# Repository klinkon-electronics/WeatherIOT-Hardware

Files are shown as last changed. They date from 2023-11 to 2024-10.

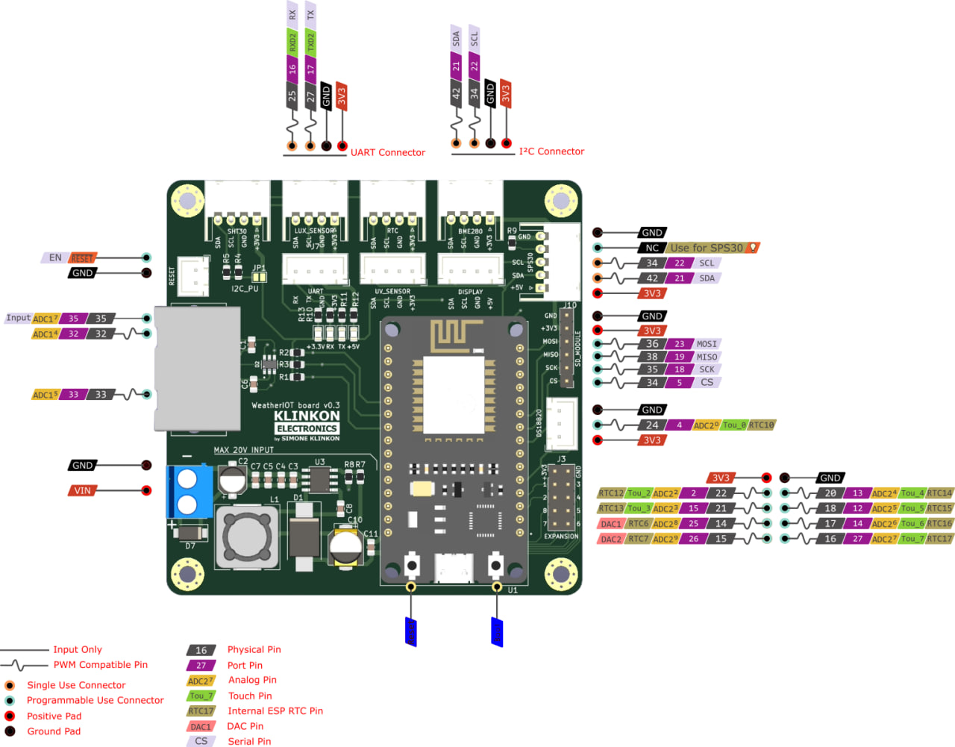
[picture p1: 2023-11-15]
WeatherIOT_0.3/pinoutWI.jpg

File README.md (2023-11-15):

# WeatherIOT-Hardware
Official repository about WeatherIOT Board and derivates (for example boards based on same hardware but with different layouts or sensors onboard)
Please contact Simone at klinkonelectronics@gmail.com or @Simoste1969 on telegram for asking mods or to upload new boards 

List of current boards:

WeatherIOT 0.3: Initial release of the board, implementing connectors for all kind of sensors, including sparkfun weather meter (anemometer and pluviometer), on board buck converter power supply (max 30V input) and ESD Protection

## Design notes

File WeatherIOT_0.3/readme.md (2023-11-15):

This is first public release of the WeatherIOT hardware

Here you can find schematics and gerbers about our full open source meteorological node, that you can use to control greenhouses, beehives, smart sprinklers, and much more, and monitoring enviroment with classic sensors as BME680, DS18B20, DHT22, and so on. Please refer to pinout of ESP32 devkit v1 to know the relative pin in the board from the pinout image. You can always contact us at klinkonelectronics@gmail.com

The interactive Bom will help you to understand position of the components and the list of materials needed to assembly the board

Here the schematic, feel free to edit that and upload your edited version in this Git repo:


second sheet about leds and expansion board


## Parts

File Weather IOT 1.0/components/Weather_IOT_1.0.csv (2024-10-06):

Reference | Value | Footprint | LCSC | LCSC-2 | Qty | DNP
C1,C4,C5 | 4.7u | Capacitor_SMD:C_0603_1608Metric | C307467 |  | 3
C2,C9,C13,C16,C18,C19 | 10u | Capacitor_SMD:C_0603_1608Metric | C96446 |  | 6
C3,C10,C11,C14,C17 | 22u | Capacitor_SMD:C_0603_1608Metric | C86295 |  | 5
C6,C7,C20,C23,C24,C25,C26,C27,C28 | 100n | Capacitor_SMD:C_0603_1608Metric | C282519 |  | 9
C8 | 120p | Capacitor_SMD:C_0603_1608Metric | C282671 |  | 1
C12 | 22n | Capacitor_SMD:C_0603_1608Metric | C21122 |  | 1
C15 | 100p | Capacitor_SMD:C_0603_1608Metric | C525236 |  | 1
C21,C22 | 1uF | Capacitor_SMD:C_0603_1608Metric | C1592 |  | 2
D1,D8 | SS34 | Diode_SMD:D_SMA | C8678 |  | 2
D2,D3 | SM4007PL | Diode_SMD:D_SOD-123F | C3008060 |  | 2
D4 | USB-CHRG | LED_SMD:LED_0805_2012Metric | C965812 |  | 1
D5 | USB-DONE | LED_SMD:LED_0805_2012Metric | C965815 |  | 1
D6 | PWR_5V | LED_SMD:LED_0805_2012Metric | C965812 |  | 1
D7 | PWR_3V3 | LED_SMD:LED_0805_2012Metric | C965812 |  | 1
D9 | RX | LED_SMD:LED_0805_2012Metric | C965813 |  | 1
D10 | TX | LED_SMD:LED_0805_2012Metric | C965813 |  | 1
D11 | DT1042-04SO-7 | _My_ic:DT1042-04SO-7 | C460064 |  | 1
D12 | CUS10S30 | Diode_SMD:D_SOD-323_HandSoldering | C146335 |  | 1
J1 | PV BOARD | Connector_PinSocket_2.54mm:PinSocket_1x05_P2.54mm_Vertical | C492404 |  | 1
J2 | 1S Battery 1 | Connector_JST:JST_XH_B2B-XH-A_1x02_P2.50mm_Vertical | C158012 |  | 1
J3 | Vin5-24V/12VFV | TerminalBlock:TerminalBlock_bornier-2_P5.08mm | C709041 |  | 1
J4 | RESET | Connector_JST:JST_XH_S2B-XH-A_1x02_P2.50mm_Horizontal | C157931 |  | 1
J5 | Wind sense | _MIA:R-RJ11R04P-A801 | C189746 |  | 1
J6 | Rain sense | _MIA:R-RJ11R04P-A801 | C189746 |  | 1
J7 | SD_module | Connector_PinHeader_2.54mm:PinHeader_1x06_P2.54mm_Horizontal | C7501615 |  | 1
J8,J10 | DS18B20 | Connector_JST:JST_XH_B3B-XH-A_1x03_P2.50mm_Vertical | C161870 |  | 2
J9 | to Expansion Board | Connector_PinSocket_2.54mm:PinSocket_1x05_P2.54mm_Vertical | C492404 |  | 1
J11 | RTC | Connector_JST:JST_XH_S4B-XH-A_1x04_P2.50mm_Horizontal | C157925 |  | 1
J12 | BME280 | Connector_JST:JST_XH_S4B-XH-A_1x04_P2.50mm_Horizontal | C157925 |  | 1
J13 | SPS30 | Connector_JST:JST_XH_S5B-XH-A_1x05_P2.50mm_Horizontal | C157925 |  | 1
J14 | Display | Connector_JST:JST_XH_S4B-XH-A_1x04_P2.50mm_Horizontal | C157925 |  | 1
J15 | EXT_UART2 | Connector_JST:JST_XH_S4B-XH-A_1x04_P2.50mm_Horizontal | C157925 |  | 1
J16 | EXPANSION_PORT | Connector_PinHeader_2.54mm:PinHeader_2x05_P2.54mm_Horizontal | C5383093 |  | 1
JP2 | no_BATT | Connector_PinHeader_2.54mm:PinHeader_1x02_P2.54mm_Vertical | C492401 | C2998928 | 1
L1 | 2.2u | Inductor_SMD:L_Chilisin_BMRA00040420 | C167206 |  | 1
L2 | 1uH | Inductor_SMD:L_Taiyo-Yuden_NR-24xx | C307851 |  | 1
R1,R4 | 100k | Resistor_SMD:R_0603_1608Metric_Pad0.98x0.95mm_HandSolder | C3016388 |  | 2
R2,R3,R7,R8,R12,R14,R15,R16,R17,R20,R21 | 1k | Resistor_SMD:R_0603_1608Metric_Pad0.98x0.95mm_HandSolder | C3016283 |  | 11
R5 | 22k | Resistor_SMD:R_0603_1608Metric_Pad0.98x0.95mm_HandSolder | C2907128 |  | 1
R6 | 30k | Resistor_SMD:R_0603_1608Metric_Pad0.98x0.95mm_HandSolder | C2907025 |  | 1
R9,R10 | 1M | Resistor_SMD:R_0603_1608Metric_Pad0.98x0.95mm_HandSolder | C3016422 |  | 2
R11 | 33k | Resistor_SMD:R_0603_1608Metric_Pad0.98x0.95mm_HandSolder | C2907028 |  | 1
R18 | 4.7k | Resistor_SMD:R_0603_1608Metric_Pad0.98x0.95mm_HandSolder | C2907034 |  | 1
R19,R22 | 10k | Resistor_SMD:R_0603_1608Metric_Pad0.98x0.95mm_HandSolder | C103199 |  | 2
U1 | TPS62A01A | Package_TO_SOT_SMD:SOT-563 | C5157937 |  | 1
U2 | TP4056 | Package_SO:HTSOP-8-1EP_3.9x4.9mm_P1.27mm_EP2.4x3.2mm_ThermalVias | C382139 |  | 1
U3 | MAX25239AFFA_VY+ | _My_ic:MAX25239AFFA_VY+ |  |  | 1
U4 | Wemos_esp32_mini | _My_boards:ESP32_mini |  |  | 1

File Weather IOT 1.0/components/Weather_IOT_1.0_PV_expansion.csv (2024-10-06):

Reference | Value | Footprint | LCSC | Qty | DNP
C1 | 330u | Capacitor_THT:CP_Radial_D8.0mm_P3.50mm | C357626 | 1
C2,C7 | 1u | Capacitor_SMD:C_0603_1608Metric | C15849 | 2
C3,C4 | 100n | Capacitor_SMD:C_0603_1608Metric | C282519 | 2
C5 | 220n | Capacitor_SMD:C_0603_1608Metric | C64705 | 1
C6 | 10u | Capacitor_SMD:C_0603_1608Metric | C96446 | 1
D1 | CHRG | LED_SMD:LED_0805_2012Metric | C965812 | 1
D2 | DONE | LED_SMD:LED_0805_2012Metric | C965815 | 1
D3,D4 | SK84 | Diode_SMD:D_SMB | C2922187 | 2
J1 | to WIoT | Connector_PinHeader_2.54mm:PinHeader_1x05_P2.54mm_Vertical | C492404 | 1
L1 | 100uH | Inductor_SMD:L_TaiTech_TMPC1265_13.5x12.5mm | C357118 | 1
Q1 | HYG210P06LQ1D | Package_TO_SOT_SMD:TO-252-2_TabPin1 | C2834760 | 1
R1 | 4.7k | Resistor_SMD:R_0603_1608Metric | C2907034 | 1
R2 | 1k | Resistor_SMD:R_0603_1608Metric | C3016283 | 1
R3 | 120 | Resistor_SMD:R_0603_1608Metric | C2906988 | 1
R4 | 120m | Resistor_SMD:R_2010_5025Metric | C3000625 | 1
RV1 | 100k | Potentiometer_THT:Potentiometer_Bourns_3296W_Vertical | C48084 | 1
U1 | CN3791 | Package_SO:SSOP-10_3.9x4.9mm_P1.00mm | C154992 | 1

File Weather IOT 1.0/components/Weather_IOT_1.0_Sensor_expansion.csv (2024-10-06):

Reference | Value | Footprint | LCSC | Qty | DNP
C6,C9 | 10u | Capacitor_SMD:C_0603_1608Metric | C96446 | 2
C8,C10 | 100n | Capacitor_SMD:C_0603_1608Metric | C282519 | 2
D1 | PWR_5V | LED_SMD:LED_0805_2012Metric | C965812 | 1
D2 | PWR_3V3 | LED_SMD:LED_0805_2012Metric | C965812 | 1
H1,H2 | MountingHole | MountingHole:MountingHole_3.2mm_M3_Pad_Via |  | 2 | DNP
J1 | LUX_Sensor | Connector_JST:JST_XH_S4B-XH-A_1x04_P2.50mm_Horizontal | C157925 | 1
J2,J5,J7 | I2C_3V3 | Connector_JST:JST_XH_B4B-XH-A_1x04_P2.50mm_Vertical | C161871 | 3
J3 | to WIoT | Connector_PinHeader_2.54mm:PinHeader_1x05_P2.54mm_Vertical |  | 1
J4 | UV_Sensor | Connector_JST:JST_XH_S4B-XH-A_1x04_P2.50mm_Horizontal | C157925 | 1
J6 | SHT30 (soil) | Connector_JST:JST_XH_S4B-XH-A_1x04_P2.50mm_Horizontal | C157925 | 1
J8 | I2C_5V | Connector_JST:JST_XH_S4B-XH-A_1x04_P2.50mm_Horizontal | C157925 | 1
J9 | I2C_5V | Connector_JST:JST_XH_B4B-XH-A_1x04_P2.50mm_Vertical | C161871 | 1
R1,R2 | 1k | Resistor_SMD:R_0603_1608Metric_Pad0.98x0.95mm_HandSolder | C3016283 | 2

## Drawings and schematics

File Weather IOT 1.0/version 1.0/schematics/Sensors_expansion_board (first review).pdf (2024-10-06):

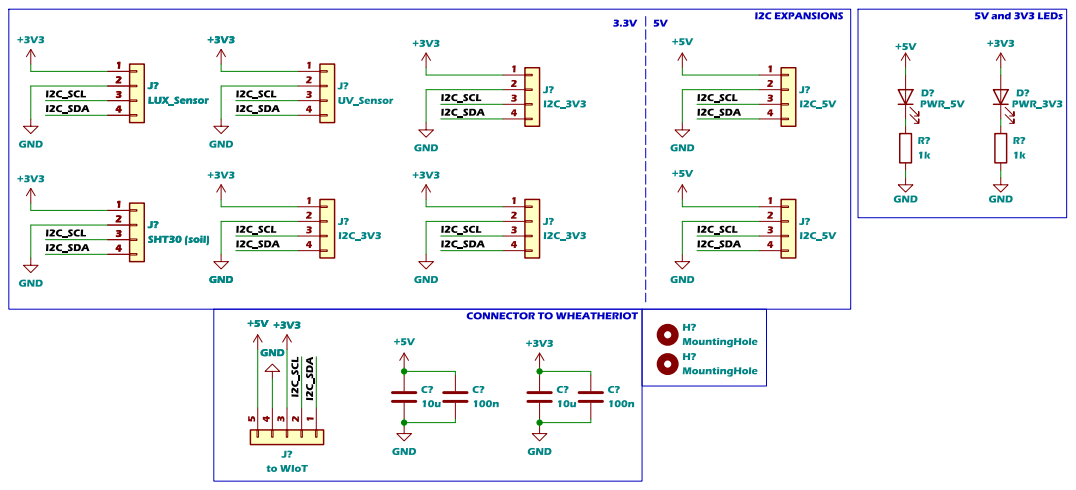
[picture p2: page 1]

5V and 3V3 LEDs 3.3V CONNECTOR TO WHEATHERIOT

File: Sensors_expansion_board.kicad_sch Sheet: / Klinkon Electronics & Floppy Lab

Id: 1/1 Title: Sensors expansion board WeatherIOT 1.0

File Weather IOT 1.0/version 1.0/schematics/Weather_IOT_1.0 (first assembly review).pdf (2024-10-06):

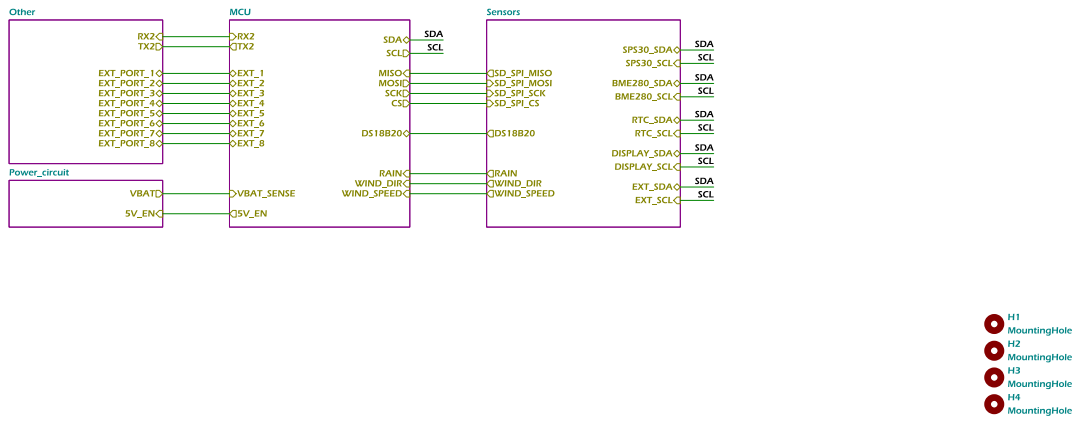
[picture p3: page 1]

File: Weather_IOT_1.0.kicad_sch Sheet: / Klinkon Electronics& Floppy Lab

Id: 1/5 Title: Weather IoT board

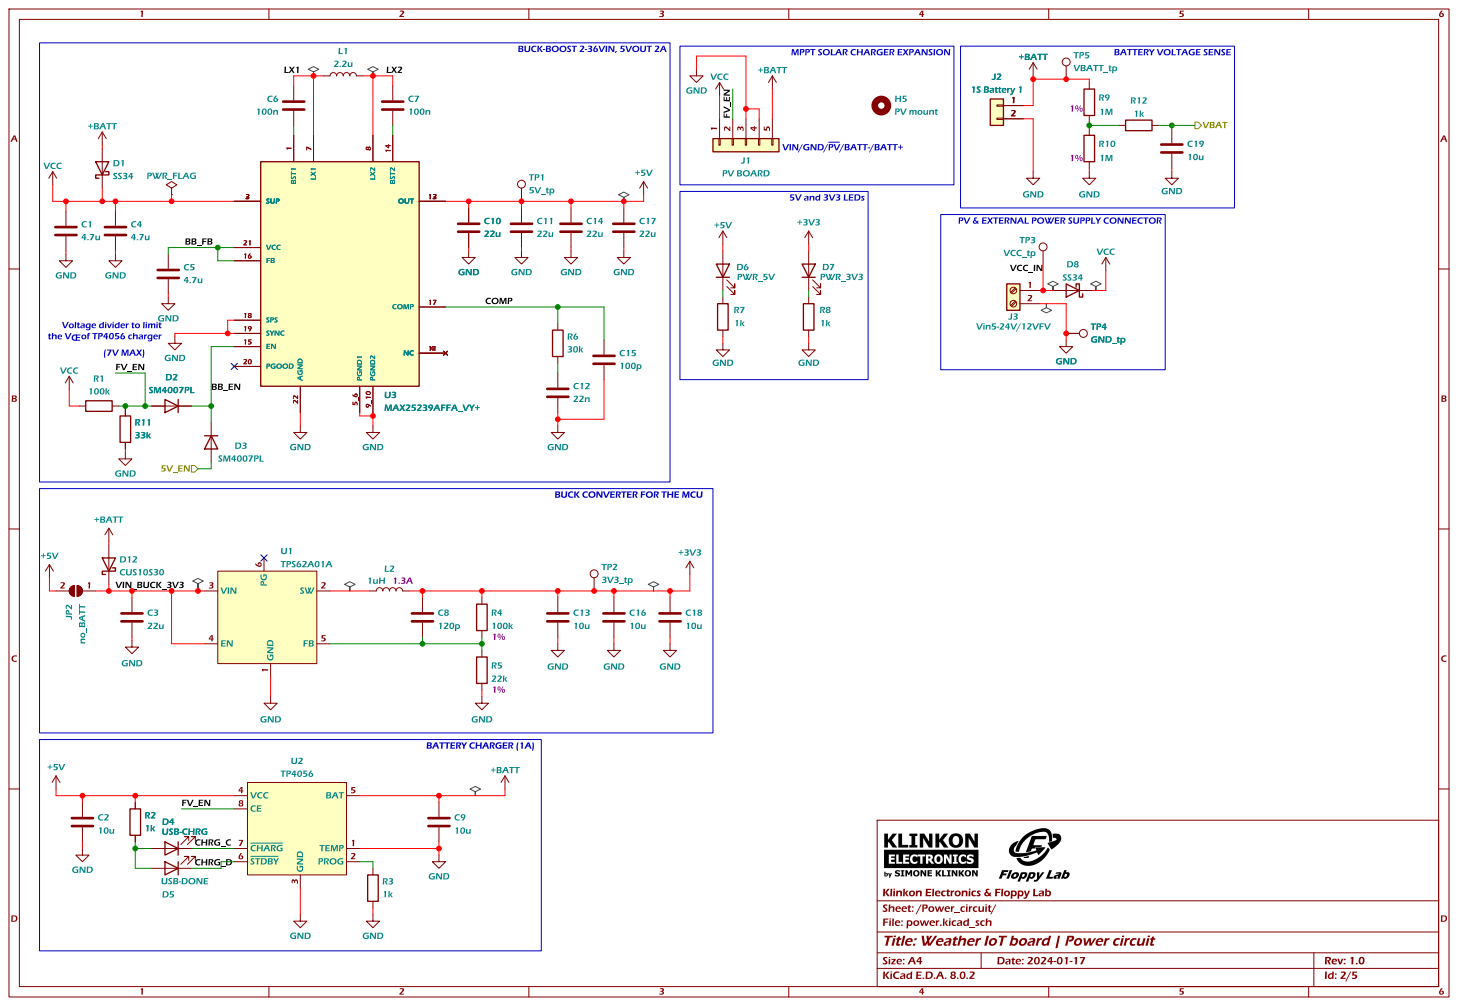
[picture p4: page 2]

VIN/GND/~{PV}/BATT-/BATT+

Voltage divider to limit

Id: 2/5 Title: Weather IoT board | Power circuit File: power.kicad_sch Sheet: /Power_circuit/ Klinkon Electronics& Floppy Lab

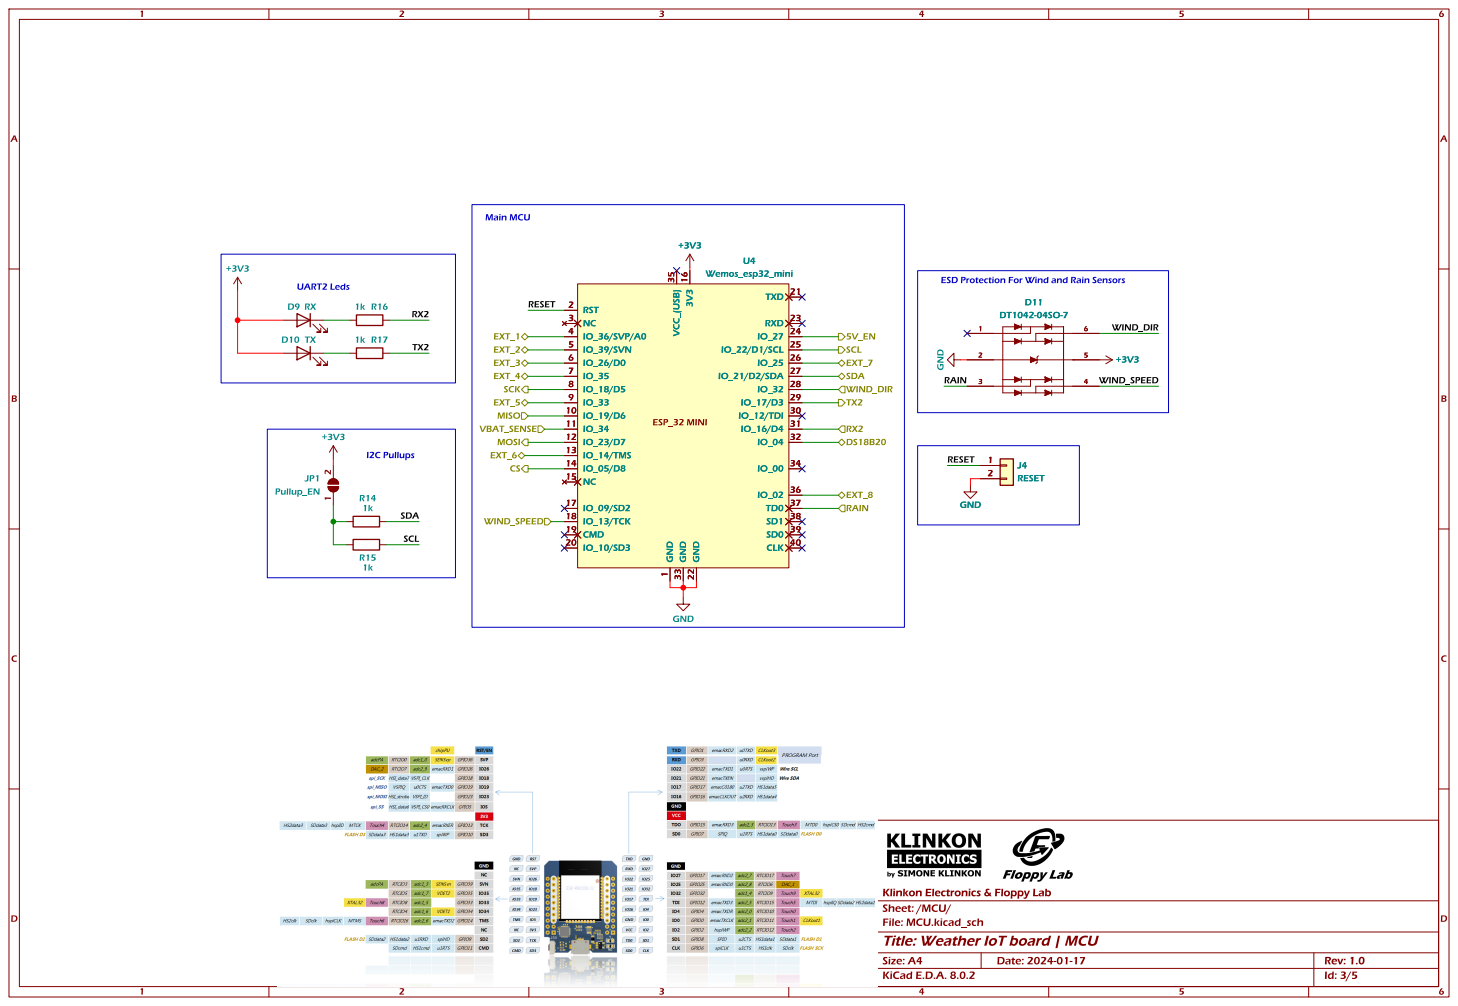
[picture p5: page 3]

ESDProtection For Wind and Rain Sensors Main MCU

File: MCU.kicad_sch Sheet: /MCU/ Klinkon Electronics& Floppy Lab

Id: 3/5 Title: Weather IoT board | MCU

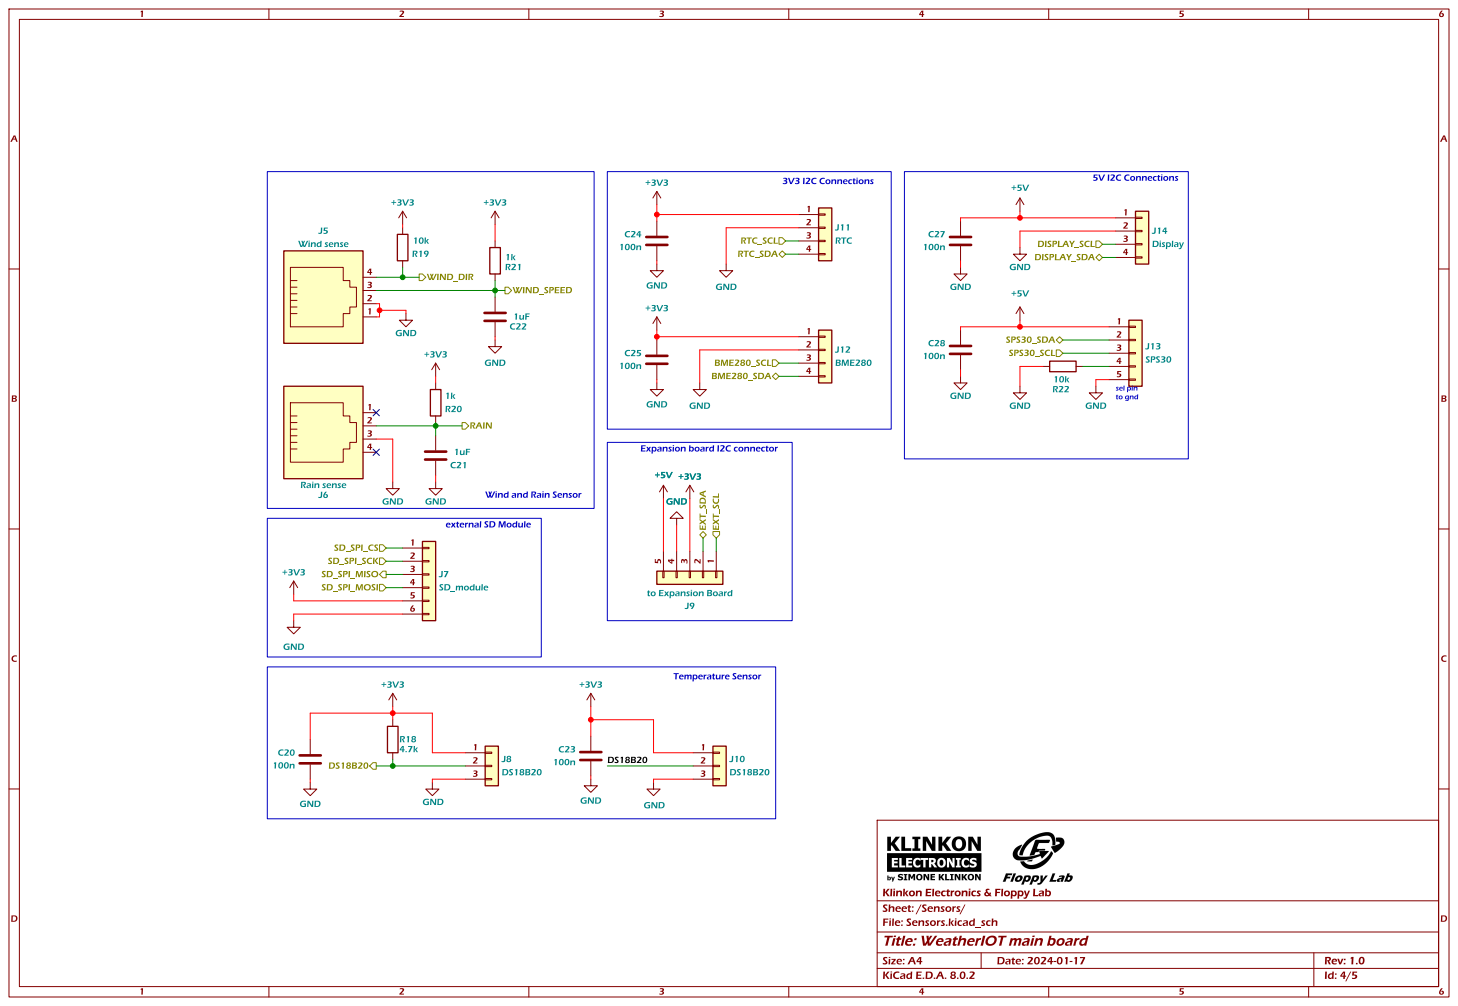
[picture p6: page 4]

File: Sensors.kicad_sch Sheet: /Sensors/ Klinkon Electronics& Floppy Lab

Id: 4/5 Title: WeatherIOT main board

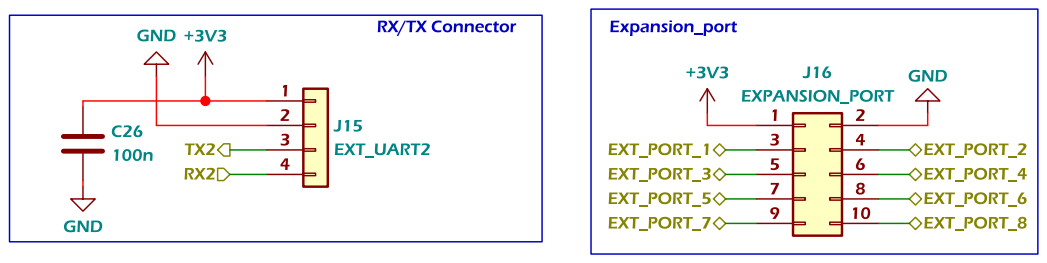
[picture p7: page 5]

Id: 5/5 Title: Weather IoT board | Other File: Other.kicad_sch Sheet: /Other/ Klinkon Electronics& Floppy Lab GND

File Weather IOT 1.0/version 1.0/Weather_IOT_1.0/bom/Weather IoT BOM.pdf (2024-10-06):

Weather IoT | Rev: 1.0

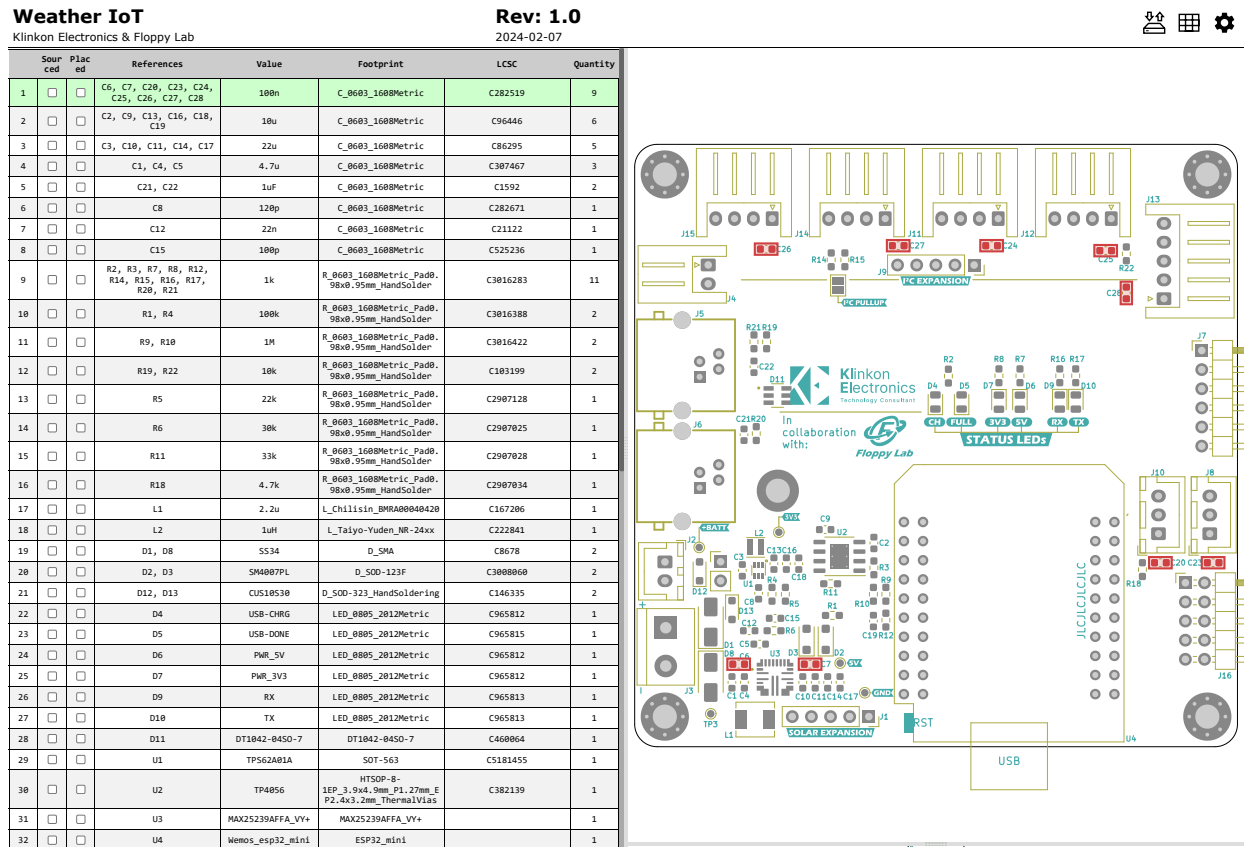
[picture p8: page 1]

Sour ced | Plac ed | References | Value | Footprint | LCSC | Quantity

1 | | | C6, C7, C20, C23, C24, C25, C26, C27, C28 | 100n | C_0603_1608Metric | C282519 | 9

2 | | | C2, C9, C13, C16, C18, C19 | 10u | C_0603_1608Metric | C96446 | 6

3 | | | C3, C10, C11, C14, C17 | 22u | C_0603_1608Metric | C86295 | 5
4 | | | C1, C4, C5 | 4.7u | C_0603_1608Metric | C307467 | 3
5 | | | C21, C22 | 1uF | C_0603_1608Metric | C1592 | 2
6 | | | C8 | 120p | C_0603_1608Metric | C282671 | 1
7 | | | C12 | 22n | C_0603_1608Metric | C21122 | 1
8 | | | C15 | 100p | C_0603_1608Metric | C525236 | 1
9 | | | R2, R3, R7, R8, R12, R14, R15, R16, R17, R20, R21 | 1k | R_0603_1608Metric_Pad0. 98x0.95mm_HandSolder | C3016283 | 11

10 | | | R1, R4 | 100k | R_0603_1608Metric_Pad0. 98x0.95mm_HandSolder | C3016388 | 2

11 | | | R9, R10 | 1M | R_0603_1608Metric_Pad0. 98x0.95mm_HandSolder | C3016422 | 2

12 | | | R19, R22 | 10k | R_0603_1608Metric_Pad0. 98x0.95mm_HandSolder | C103199 | 2

13 | | | R5 | 22k | R_0603_1608Metric_Pad0. 98x0.95mm_HandSolder | C2907128 | 1

14 | | | R6 | 30k | R_0603_1608Metric_Pad0. 98x0.95mm_HandSolder | C2907025 | 1

15 | | | R11 | 33k | R_0603_1608Metric_Pad0. 98x0.95mm_HandSolder | C2907028 | 1

16 | | | R18 | 4.7k | R_0603_1608Metric_Pad0. 98x0.95mm_HandSolder | C2907034 | 1

17 | | | L1 | 2.2u | L_Chilisin_BMRA00040420 | C167206 | 1
18 | | | L2 | 1uH | L_Taiyo-Yuden_NR-24xx | C222841 | 1
19 | | | D1, D8 | SS34 | D_SMA | C8678 | 2
20 | | | D2, D3 | SM4007PL | D_SOD-123F | C3008060 | 2
21 | | | D12, D13 | CUS10S30 | D_SOD-323_HandSoldering | C146335 | 2
22 | | | D4 | USB-CHRG | LED_0805_2012Metric | C965812 | 1
23 | | | D5 | USB-DONE | LED_0805_2012Metric | C965815 | 1
24 | | | D6 | PWR_5V | LED_0805_2012Metric | C965812 | 1
25 | | | D7 | PWR_3V3 | LED_0805_2012Metric | C965812 | 1
26 | | | D9 | RX | LED_0805_2012Metric | C965813 | 1
27 | | | D10 | TX | LED_0805_2012Metric | C965813 | 1
28 | | | D11 | DT1042-04SO-7 | DT1042-04SO-7 | C460064 | 1
29 | | | U1 | TPS62A01A | SOT-563 | C5181455 | 1
30 | | | U2 | TP4056 | HTSOP-8-1EP_3.9x4.9mm_P1.27mm_E P2.4x3.2mm_ThermalVias | C382139 | 1

31 | | | U3 | MAX25239AFFA_VY+ | MAX25239AFFA_VY+ | | 1

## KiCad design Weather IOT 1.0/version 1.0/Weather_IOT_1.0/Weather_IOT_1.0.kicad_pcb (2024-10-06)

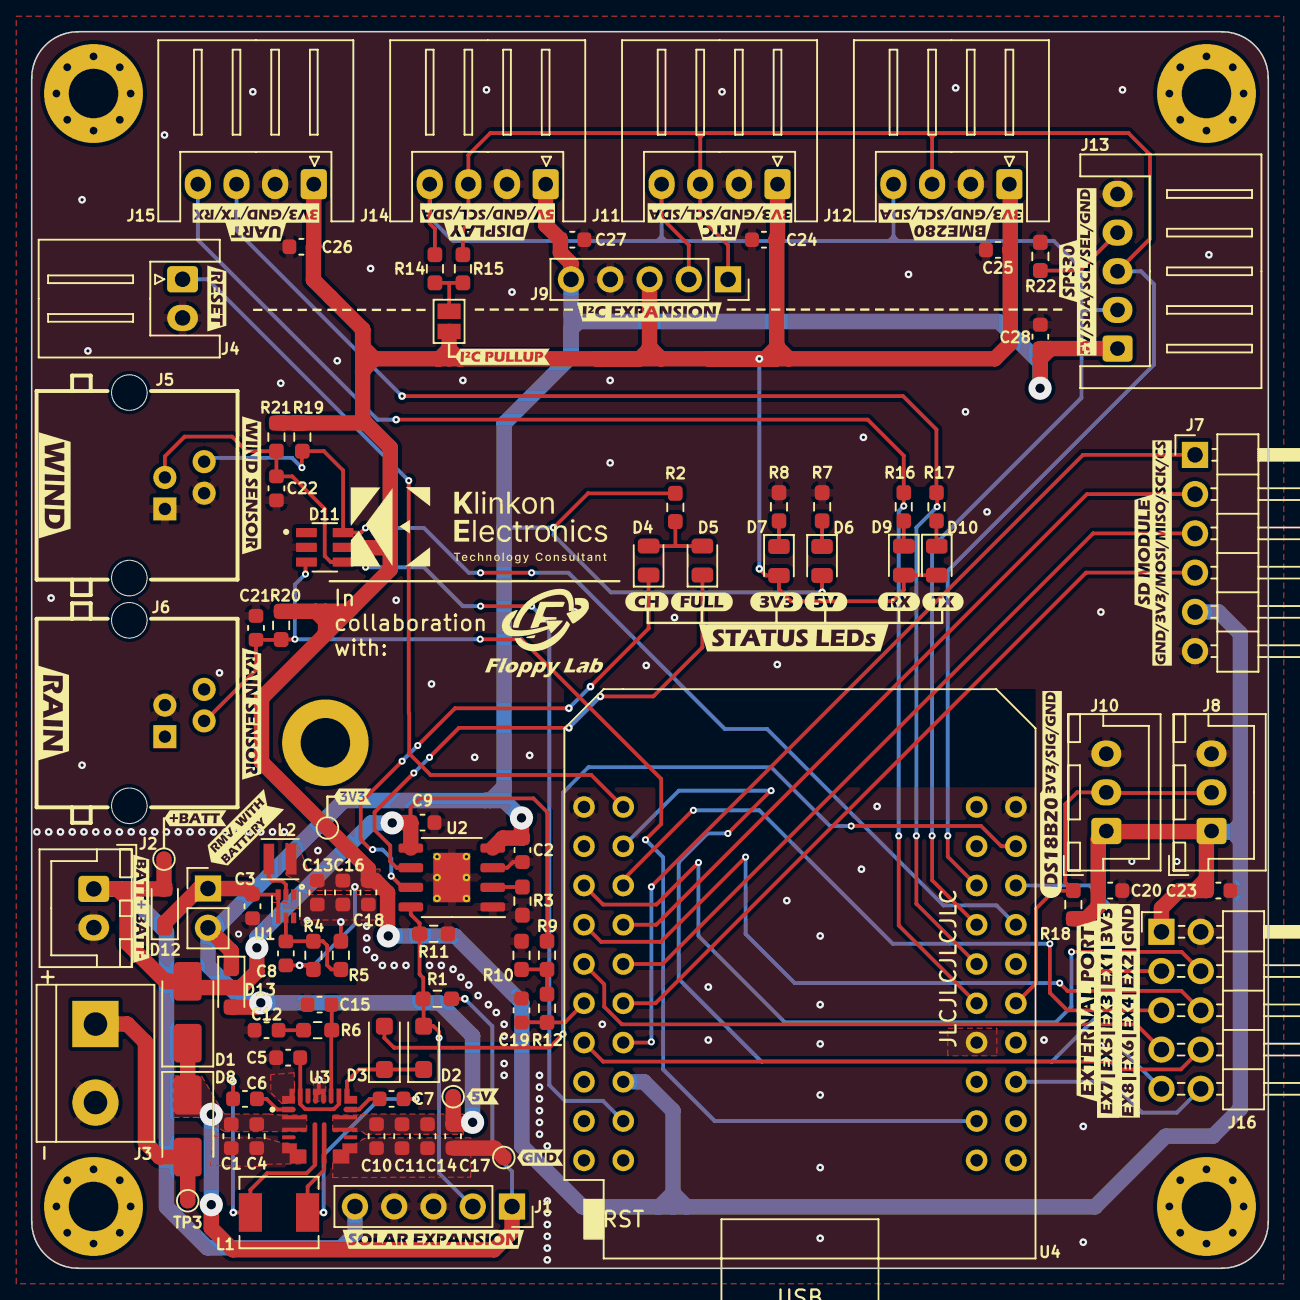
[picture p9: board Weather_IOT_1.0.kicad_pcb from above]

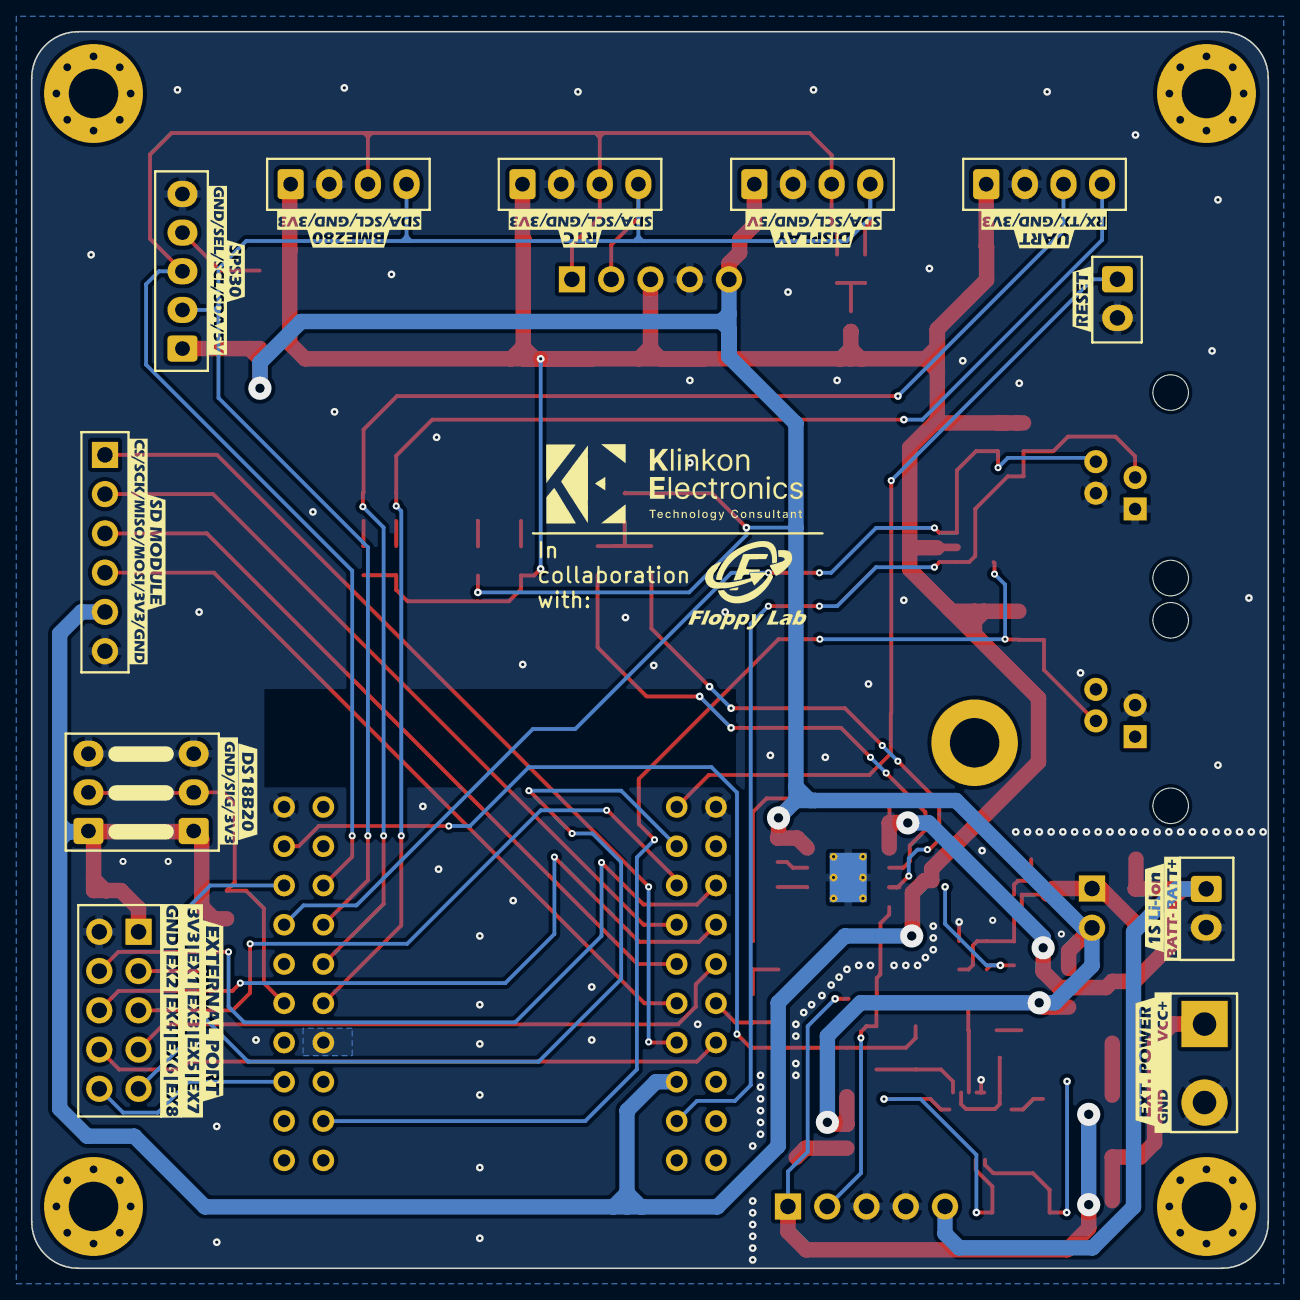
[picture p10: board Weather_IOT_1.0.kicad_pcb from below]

Board: 2 copper layers, 80.0 x 80.0 mm, 156 parts (22 on the bottom side), 52 nets.

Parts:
C1, C4, C5: 4.7u; C_0603_1608Metric
C2, C9, C13, C16, C18, C19: 10u; C_0603_1608Metric
C3, C10, C11, C14, C17: 22u; C_0603_1608Metric
C6, C7, C20, C23, C24, C25, C26, C27, C28: 100n; C_0603_1608Metric
C8: 120p; C_0603_1608Metric
C12: 22n; C_0603_1608Metric
C15: 100p; C_0603_1608Metric
C21, C22: 1uF; C_0603_1608Metric
D1, D8: SS34; D_SMA
D2, D3: SM4007PL; D_SOD-123F
D4: USB-CHRG; LED_0805_2012Metric
D5: USB-DONE; LED_0805_2012Metric
D6: PWR_5V; LED_0805_2012Metric
D7: PWR_3V3; LED_0805_2012Metric
D9: RX; LED_0805_2012Metric
D10: TX; LED_0805_2012Metric
D11: DT1042-04SO-7
D12, D13: CUS10S30; D_SOD-323_HandSoldering
H1, H2, H3, H4: MountingHole; MountingHole_3.2mm_M3_Pad_Via
H5: PV mount; MountingHole_3.2mm_M3_DIN965_Pad
J1: PV BOARD; PinSocket_1x05_P2.54mm_Vertical
J2: 1S Battery 1; JST_XH_B2B-XH-A_1x02_P2.50mm_Vertical
J3: Vin5-24V/12VFV; TerminalBlock_bornier-2_P5.08mm
J4: RESET; JST_XH_S2B-XH-A_1x02_P2.50mm_Horizontal
J5: Wind sense; R-RJ11R04P-A801
J6: Rain sense; R-RJ11R04P-A801
J7: SD_module; PinHeader_1x06_P2.54mm_Horizontal
J8, J10: DS18B20; JST_XH_B3B-XH-A_1x03_P2.50mm_Vertical
J9: to Expansion Board; PinSocket_1x05_P2.54mm_Vertical
J11: RTC; JST_XH_S4B-XH-A_1x04_P2.50mm_Horizontal
J12: BME280; JST_XH_S4B-XH-A_1x04_P2.50mm_Horizontal
J13: SPS30; JST_XH_S5B-XH-A_1x05_P2.50mm_Horizontal
J14: Display; JST_XH_S4B-XH-A_1x04_P2.50mm_Horizontal
J15: EXT_UART2; JST_XH_S4B-XH-A_1x04_P2.50mm_Horizontal
J16: EXPANSION_PORT; PinHeader_2x05_P2.54mm_Horizontal
JP1: Pullup_EN; SolderJumper-2_P1.3mm_Open_Pad1.0x1.5mm
JP2: no_BATT; PinHeader_1x02_P2.54mm_Vertical
L1: 2.2u; L_Chilisin_BMRA00040420
L2: 1uH; L_Taiyo-Yuden_NR-24xx
R1, R4: 100k; R_0603_1608Metric_Pad0.98x0.95mm_HandSolder
R2, R3, R7, R8, R12, R14, R15, R16, R17, R20, R21: 1k; R_0603_1608Metric_Pad0.98x0.95mm_HandSolder
R5: 22k; R_0603_1608Metric_Pad0.98x0.95mm_HandSolder
R6: 30k; R_0603_1608Metric_Pad0.98x0.95mm_HandSolder
R9, R10: 1M; R_0603_1608Metric_Pad0.98x0.95mm_HandSolder
R11: 33k; R_0603_1608Metric_Pad0.98x0.95mm_HandSolder
R18: 4.7k; R_0603_1608Metric_Pad0.98x0.95mm_HandSolder
R19, R22: 10k; R_0603_1608Metric_Pad0.98x0.95mm_HandSolder
TP1: 5V_tp; TestPoint_Pad_D1.0mm
TP2: 3V3_tp; TestPoint_Pad_D1.0mm
TP3: VCC_tp; TestPoint_Pad_D1.0mm
TP4: GND_tp; TestPoint_Pad_D1.0mm
TP5: VBATT_tp; TestPoint_Pad_D1.0mm
U1: TPS62A01A; SOT-563
U2: TP4056; HTSOP-8-1EP_3.9x4.9mm_P1.27mm_EP2.4x3.2mm_ThermalVias
U3: MAX25239AFFA_VY+
U4: Wemos_esp32_mini; ESP32_mini
kibuzzard-65C5F9F0: G***; kibuzzard-65C5F9F0
kibuzzard-65C5F9FB: G***; kibuzzard-65C5F9FB
kibuzzard-65C5F84F: G***; kibuzzard-65C5F84F
kibuzzard-65C5F840: G***; kibuzzard-65C5F840
kibuzzard-65C5FA29: G***; kibuzzard-65C5FA29
kibuzzard-65C5FA31: G***; kibuzzard-65C5FA31
kibuzzard-65C5FAB1, kibuzzard-65C5FAB1#2: G***; kibuzzard-65C5FAB1
kibuzzard-65C5FC57, kibuzzard-65C5FC57#2: G***; kibuzzard-65C5FC57
kibuzzard-65C5FCAF: G***; kibuzzard-65C5FCAF
kibuzzard-65C5FCBA: G***; kibuzzard-65C5FCBA
kibuzzard-65C5FCD1, kibuzzard-65C5FCD1#2: G***; kibuzzard-65C5FCD1
kibuzzard-65C5FCD9, kibuzzard-65C5FCD9#2: G***; kibuzzard-65C5FCD9
kibuzzard-65C5FCF3, kibuzzard-65C5FCF3#2: G***; kibuzzard-65C5FCF3
kibuzzard-65C5FD65, kibuzzard-65C5FD65#2: G***; kibuzzard-65C5FD65
kibuzzard-65C5FDCF: G***; kibuzzard-65C5FDCF
kibuzzard-65C5FDF5, kibuzzard-65C5FDF5#2: G***; kibuzzard-65C5FDF5
kibuzzard-65C5FE80: G***; kibuzzard-65C5FE80
kibuzzard-65C5FF49: G***; kibuzzard-65C5FF49
kibuzzard-65C5FF79: G***; kibuzzard-65C5FF79
kibuzzard-65C60A60: G***; kibuzzard-65C60A60
kibuzzard-65C60B28: G***; kibuzzard-65C60B28
kibuzzard-65C60C38: G***; kibuzzard-65C60C38
kibuzzard-65C60D2D: G***; kibuzzard-65C60D2D
kibuzzard-65C60D73: G***; kibuzzard-65C60D73
kibuzzard-65C60D82: G***; kibuzzard-65C60D82
kibuzzard-65C604B4: G***; kibuzzard-65C604B4
kibuzzard-65C604F6, kibuzzard-65C604F6#2: G***; kibuzzard-65C604F6
kibuzzard-65C608BF: G***; kibuzzard-65C608BF
kibuzzard-65C609AB, kibuzzard-65C609AB#2: G***; kibuzzard-65C609AB
kibuzzard-65C643D1: G***; kibuzzard-65C643D1
kibuzzard-65C643E1: G***; kibuzzard-65C643E1
kibuzzard-65C643FB: G***; kibuzzard-65C643FB
kibuzzard-65C643FF: G***; kibuzzard-65C643FF
kibuzzard-65C644A3: G***; kibuzzard-65C644A3
kibuzzard-65C644F8: G***; kibuzzard-65C644F8
kibuzzard-65C645B8: G***; kibuzzard-65C645B8
kibuzzard-65C648A6: G***; kibuzzard-65C648A6
kibuzzard-65C6048B: G***; kibuzzard-65C6048B
kibuzzard-65C6062C: G***; kibuzzard-65C6062C
kibuzzard-65C6116C: G***; kibuzzard-65C6116C
kibuzzard-65C6441A: G***; kibuzzard-65C6441A
kibuzzard-65C6444D: G***; kibuzzard-65C6444D
kibuzzard-65C60624: G***; kibuzzard-65C60624
kibuzzard-65C60828: G***; kibuzzard-65C60828
kibuzzard-65C60923: G***; kibuzzard-65C60923
kibuzzard-65C61177: G***; kibuzzard-65C61177
kibuzzard-65C64431: G***; kibuzzard-65C64431
kibuzzard-65C64477: G***; kibuzzard-65C64477
kibuzzard-65C64545: G***; kibuzzard-65C64545
kibuzzard-65C64592: G***; kibuzzard-65C64592
kibuzzard-65E8D7FD: G***; kibuzzard-65E8D7FD

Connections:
+3V3: C8.1, C13.1, C16.1, C18.1, C20.1, C23.1, C24.1, C25.1, C26.1, D7.2 (A), D9.2 (A), D10.2 (A), D11.5, J7.5, J8.1, J9.3, J10.1, J11.1, J12.1, J15.1, J16.1, JP1.2 (B), L2.2, R4.1, R18.1, R19.2, R20.2, R21.1, TP2.1, U4.16 (3V3)
+5V: C2.1, C10.1, C11.1, C14.1, C17.1, C27.1, C28.1, D6.2 (A), D13.2 (A), J9.5, J13.1, J14.1, JP2.2 (B), R2.2, TP1.1, U2.4 (VCC), U3.12 (OUT), U3.13 (OUT)
+BATT: C9.1, D1.2 (A), D12.2 (A), J1.5, J2.1, R9.1, TP5.1, U2.5 (BAT)
/MCU/5V_EN: D3.2 (A), U4.24 (IO_27)
/MCU/CS: J7.1, U4.14 (IO_05/D8)
/MCU/EXT_1: J16.3, U4.4 (IO_36/SVP/A0)
/MCU/EXT_2: J16.4, U4.5 (IO_39/SVN)
/MCU/EXT_3: J16.5, U4.6 (IO_26/D0)
/MCU/EXT_4: J16.6, U4.7 (IO_35)
/MCU/EXT_5: J16.7, U4.9 (IO_33)
/MCU/EXT_6: J16.8, U4.13 (IO_14/TMS)
/MCU/EXT_7: J16.9, U4.26 (IO_25)
/MCU/EXT_8: J16.10, U4.36 (IO_02)
/MCU/MISO: J7.3, U4.10 (IO_19/D6)
/MCU/MOSI: J7.4, U4.12 (IO_23/D7)
/MCU/RAIN: C21.2, D11.3, J6.2, R20.1, U4.37 (TD0)
/MCU/RESET: J4.1, U4.2 (RST)
/MCU/RX2: J15.4, R16.1, U4.31 (IO_16/D4)
/MCU/SCK: J7.2, U4.8 (IO_18/D5)
/MCU/TX2: J15.3, R17.1, U4.29 (IO_17/D3)
/MCU/VBAT_SENSE: C19.1, R12.2, U4.11 (IO_34)
/MCU/WIND_DIR: D11.6, J5.4, R19.1, U4.28 (IO_32)
/MCU/WIND_SPEED: C22.2, D11.4, J5.3, R21.2, U4.18 (IO_13/TCK)
/Power_circuit/BB_EN: D2.1 (K), D3.1 (K), U3.15 (EN)
/Power_circuit/BB_FB: C5.1, U3.16 (FB), U3.21 (VCC)
/Power_circuit/CHRG_C: D4.1 (K), U2.7 (~CHARG)
/Power_circuit/CHRG_D: D5.1 (K), U2.6 (~STDBY)
/Power_circuit/COMP: C15.1, R6.1, U3.17 (COMP)
/Power_circuit/FV_EN: D2.2 (A), J1.2, R1.1, R11.1, U2.8 (CE)
/Power_circuit/LX1: C6.1, L1.1, U3.7 (LX1)
/Power_circuit/LX2: C7.1, L1.2, U3.8 (LX2)
/Power_circuit/VCC_IN: D8.2 (A), J3.1, TP3.1
/Power_circuit/VIN_BUCK_3V3: C3.1, D12.1 (K), JP2.1 (A), U1.3 (VIN), U1.4 (EN)
/SCL: J9.1, J11.3, J12.3, J13.3, J14.3, R15.2, U4.25 (IO_22/D1/SCL)
/SDA: J9.2, J11.4, J12.4, J13.2, J14.4, R14.2, U4.27 (IO_21/D2/SDA)
/Sensors/DS18B20: J8.2, J10.2, R18.2, U4.32 (IO_04)
GND: C1.2, C2.2, C3.2, C4.2, C5.2, C9.2, C10.2, C11.2, C12.2, C13.2, C14.2, C15.2, C16.2, C17.2, C18.2, C19.2, C20.2, C21.1, C22.1, C23.2, C24.2, C25.2, C26.2, C27.2, C28.2, D11.2, J1.3, J1.4, J2.2, J3.2, J4.2, J5.1, J5.2, J6.3, J7.6, J8.3, J9.4, J10.3, J11.2, J12.2, J13.5, J14.2, J15.2, J16.2, R3.2, R5.2, R7.1, R8.1, R10.2, R11.2, R22.1, TP4.1, U1.1 (GND), U2.1 (TEMP), U2.3 (GND), U3.5_6 (PGND1), U3.9_10 (PGND2), U3.18 (SPS), U3.19 (SYNC), U3.22 (AGND), U4.1 (GND), U4.22 (GND), U4.33 (GND)
unnamed: C12.1, R6.2
unnamed: D4.2 (A), D5.2 (A), R2.1
unnamed: D6.1 (K), R7.2
unnamed: D7.1 (K), R8.2
unnamed: D9.1 (K), R16.2
unnamed: D10.1 (K), R17.2
unnamed: J13.4, R22.2
unnamed: JP1.1 (A), R14.1, R15.1
unnamed: R9.2, R10.1, R12.1
unnamed: C8.2, R4.2, R5.1, U1.5 (FB)
unnamed: L2.1, U1.2 (SW)
unnamed: R3.1, U2.2 (PROG)
unnamed: C6.2, U3.1 (BST1)
unnamed: C7.2, U3.14 (BST2)
VCC: C1.1, C4.1, D1.1 (K), D8.1 (K), J1.1, R1.2, U3.2 (SUP), U3.3 (SUP)

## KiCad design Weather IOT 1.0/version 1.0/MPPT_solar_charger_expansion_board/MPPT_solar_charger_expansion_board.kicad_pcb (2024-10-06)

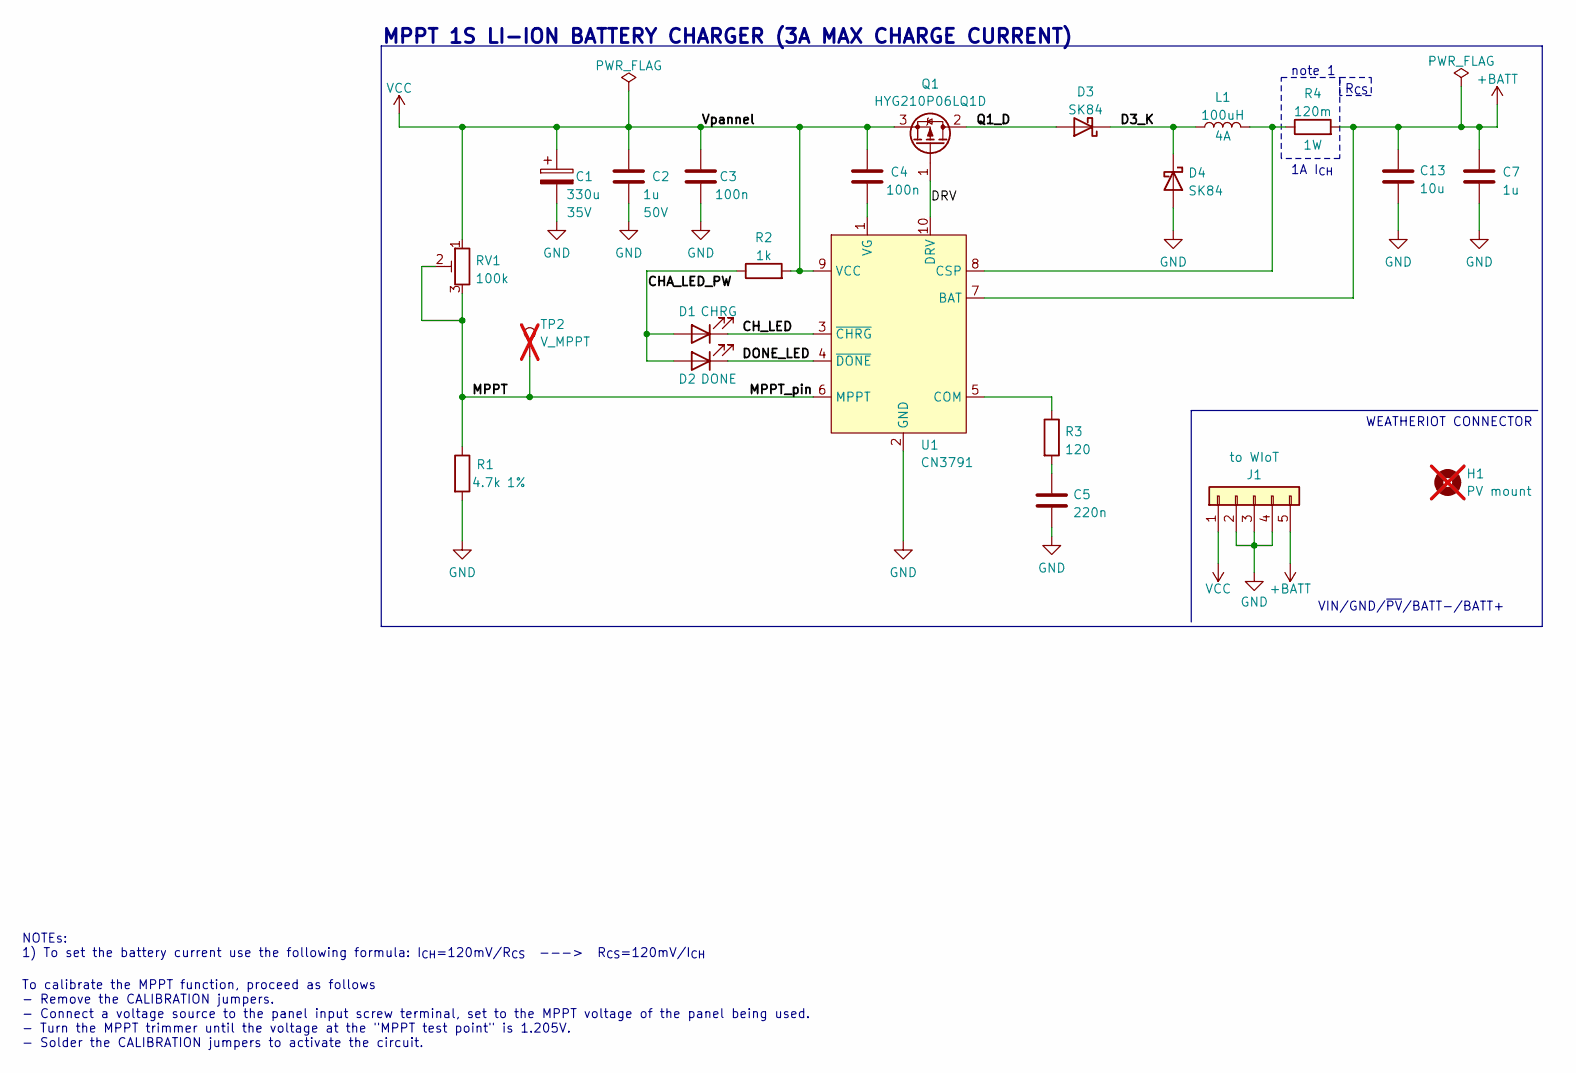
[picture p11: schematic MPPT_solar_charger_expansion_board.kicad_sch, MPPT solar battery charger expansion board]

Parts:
C1: 330u; CP_Radial_D8.0mm_P3.50mm; Voltage 35V; LCSC C357626
C2, C7: 1u; C_0603_1608Metric; Voltage 50V; LCSC C15849
C3, C4: 100n; C_0603_1608Metric; Voltage 50V; LCSC C282519
C5: 220n; C_0603_1608Metric; Voltage 50V; LCSC C64705
C13: 10u; C_0603_1608Metric; LCSC C96446
D1: CHRG; LED_0805_2012Metric; LCSC C965812
D2: DONE; LED_0805_2012Metric; LCSC C965815
D3, D4: SK84; D_SMB; LCSC C2922187
H1: PV mount; MountingHole_3.2mm_M3_ISO7380_Pad; not fitted
J1: to WIoT; PinHeader_1x05_P2.54mm_Vertical; LCSC C492404
L1: 100uH; L_TaiTech_TMPC1265_13.5x12.5mm; LCSC C357118
Q1: HYG210P06LQ1D; TO-252-2_TabPin1; LCSC C2834760
R1: 4.7k; R_0603_1608Metric; LCSC C2907034
R2: 1k; R_0603_1608Metric; LCSC C3016283
R3: 120; R_0603_1608Metric; LCSC C2906988
R4: 120m; R_2010_5025Metric; LCSC C3000625
RV1: 100k; Potentiometer_Bourns_3296W_Vertical; LCSC C48084
TP2: V_MPPT; TestPoint_THTPad_D1.5mm_Drill0.7mm; not fitted
U1: CN3791; SSOP-10_3.9x4.9mm_P1.00mm; LCSC C154992

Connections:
+BATT: C7.1, J1.5, R4.2, U1.7 (BAT); also elsewhere on the board
/CHA_LED_PW: D1.2 (A), D2.2 (A), R2.1
/CH_LED: D1.1 (K), U1.3 (~CHRG)
/D3_K: D3.1 (K), D4.1 (K), L1.1
/DONE_LED: D2.1 (K), U1.4 (~DONE)
/DRV: Q1.1 (G), U1.10 (DRV)
/MPPT: R1.1, RV1.2, RV1.3, TP2.1, U1.6 (MPPT)
/Q1_D: D3.2 (A), Q1.2 (D)
GND: C1.2, C2.2, C3.2, C5.2, C7.2, D4.2 (A), J1.2, J1.3, J1.4, R1.2, U1.2 (GND); also elsewhere on the board
unnamed: C5.1, R3.2
unnamed: R3.1, U1.5 (COM)
unnamed: L1.2, R4.1, U1.8 (CSP)
unnamed: C4.2, U1.1 (VG)
VCC: C1.1, C2.1, C3.1, C4.1, J1.1, Q1.3 (S), R2.2, RV1.1, U1.9 (VCC)

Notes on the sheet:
MPPT 1S LI-ION BATTERY CHARGER (3A MAX CHARGE CURRENT)
note 1
R_{CS}
To calibrate the MPPT function, proceed as follows - Remove the CALIBRATION jumpers. - Connect a voltage source to the panel input screw terminal, set to the MPPT voltage of the panel being used. - Turn the MPPT trimmer until the voltage at the "MPPT test point" is 1.205V. - Solder the CALIBRATION 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
VIN/GND/~{PV}/BATT-/BATT+
1A I_{CH}
WEATHERIOT CONNECTOR
NOTEs: 1) To set the battery current use the following formula: I_{CH}=120mV/R_{CS} ---> R_{CS}=120mV/I_{CH}

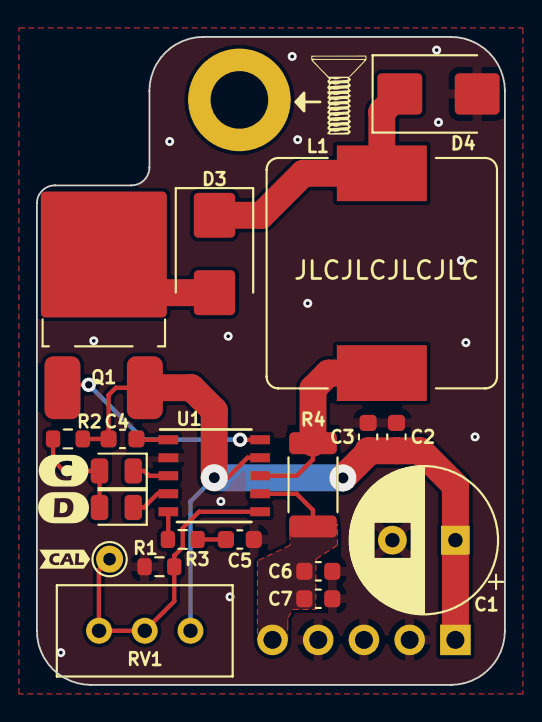
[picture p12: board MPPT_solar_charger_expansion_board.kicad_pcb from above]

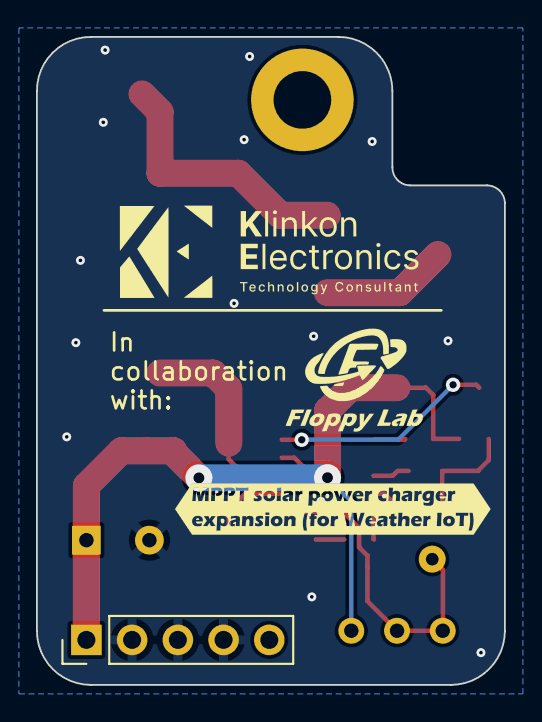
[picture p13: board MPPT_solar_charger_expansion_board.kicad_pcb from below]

Board: 2 copper layers, 26.0 x 36.0 mm, 26 parts (2 on the bottom side), 14 nets.

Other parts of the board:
C6: 10u; C_0603_1608Metric
kibuzzard-65C7DFB2: G***; kibuzzard-65C7DFB2
kibuzzard-65C7E01B: G***; kibuzzard-65C7E01B
kibuzzard-65C7E026: G***; kibuzzard-65C7E026
kibuzzard-65C8E163: G***; kibuzzard-65C8E163

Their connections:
+BATT: C6.1; also elsewhere on the board
GND: C6.2; also elsewhere on the board

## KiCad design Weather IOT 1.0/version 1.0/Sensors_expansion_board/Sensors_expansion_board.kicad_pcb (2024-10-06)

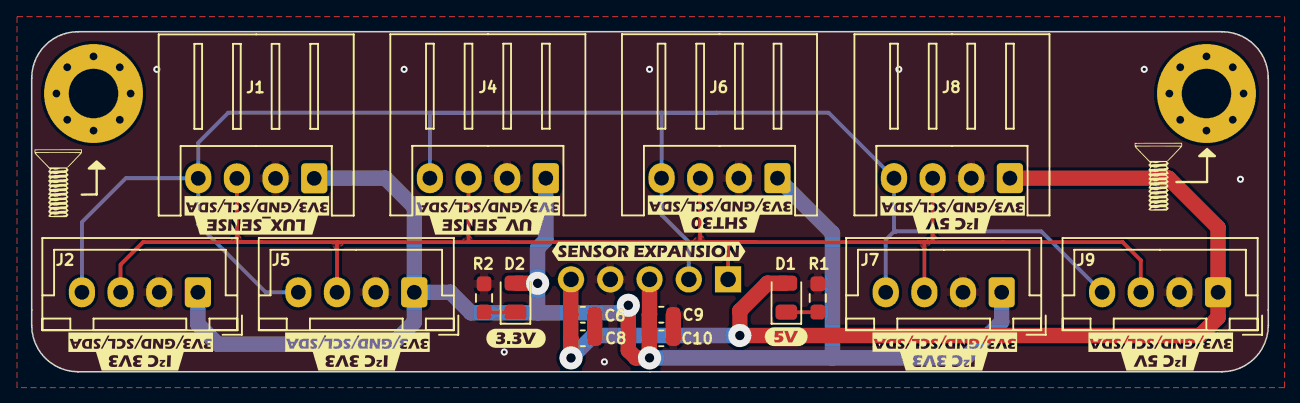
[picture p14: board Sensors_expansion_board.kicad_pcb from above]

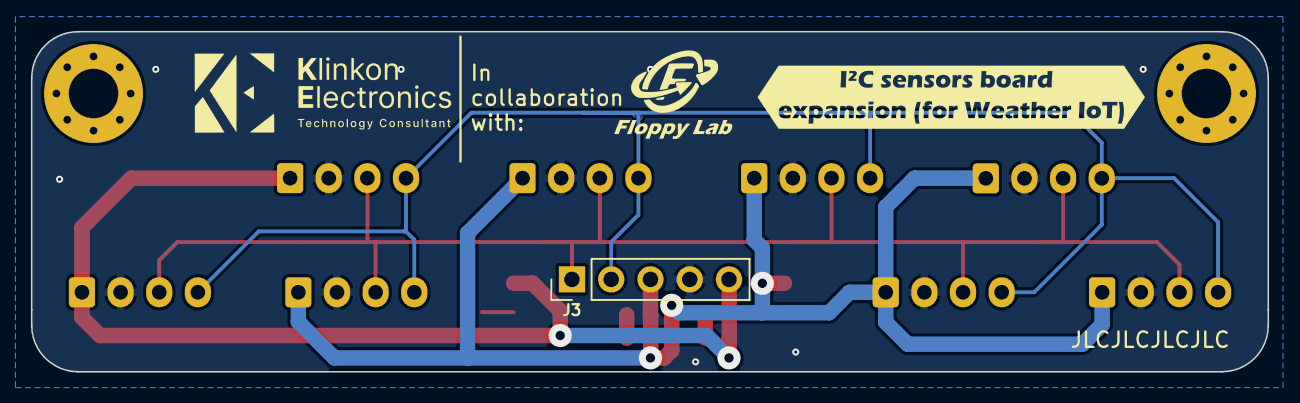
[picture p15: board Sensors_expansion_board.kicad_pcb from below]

Board: 2 copper layers, 80.0 x 22.0 mm, 39 parts (2 on the bottom side), 7 nets.

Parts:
C6, C9: 10u; C_0603_1608Metric
C8, C10: 100n; C_0603_1608Metric
D1: PWR_5V; LED_0805_2012Metric
D2: PWR_3V3; LED_0805_2012Metric
H1, H2: MountingHole; MountingHole_3.2mm_M3_Pad_Via
J1: LUX_Sensor; JST_XH_S4B-XH-A_1x04_P2.50mm_Horizontal
J2, J5, J7: I2C_3V3; JST_XH_B4B-XH-A_1x04_P2.50mm_Vertical
J3: to WIoT; PinHeader_1x05_P2.54mm_Vertical
J4: UV_Sensor; JST_XH_S4B-XH-A_1x04_P2.50mm_Horizontal
J6: SHT30 (soil); JST_XH_S4B-XH-A_1x04_P2.50mm_Horizontal
J8: I2C_5V; JST_XH_S4B-XH-A_1x04_P2.50mm_Horizontal
J9: I2C_5V; JST_XH_B4B-XH-A_1x04_P2.50mm_Vertical
R1, R2: 1k; R_0603_1608Metric_Pad0.98x0.95mm_HandSolder
kibuzzard-65C5FCD9, kibuzzard-65C5FCD9#2, kibuzzard-65C5FCD9#3, kibuzzard-65C5FCD9#4, kibuzzard-65C5FCD9#5, kibuzzard-65C5FCD9#6, kibuzzard-65C5FCD9#7, kibuzzard-65C5FCD9#8: G***; kibuzzard-65C5FCD9
kibuzzard-65C8D7CB: G***; kibuzzard-65C8D7CB
kibuzzard-65C8D7D6: G***; kibuzzard-65C8D7D6
kibuzzard-65C8D7E5: G***; kibuzzard-65C8D7E5
kibuzzard-65C8D72A, kibuzzard-65C8D72A#2, kibuzzard-65C8D72A#3: G***; kibuzzard-65C8D72A
kibuzzard-65C8D780, kibuzzard-65C8D780#2: G***; kibuzzard-65C8D780
kibuzzard-65C8D846: G***; kibuzzard-65C8D846
kibuzzard-65C8D862: G***; kibuzzard-65C8D862
kibuzzard-65C8E45A: G***; kibuzzard-65C8E45A
kibuzzard-65C8E424: G***; kibuzzard-65C8E424

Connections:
+3V3: C9.1, C10.1, D2.2 (A), J1.1, J2.1, J3.3, J4.1, J5.1, J6.1, J7.1
+5V: C6.1, C8.1, D1.2 (A), J3.5, J8.1, J9.1
/I2C_SCL: J1.3, J2.3, J3.1, J4.3, J5.3, J6.3, J7.3, J8.3, J9.3
/I2C_SDA: J1.4, J2.4, J3.2, J4.4, J5.4, J6.4, J7.4, J8.4, J9.4
GND: C6.2, C8.2, C9.2, C10.2, J1.2, J2.2, J3.4, J4.2, J5.2, J6.2, J7.2, J8.2, J9.2, R1.1, R2.1
unnamed: D1.1 (K), R1.2
unnamed: D2.1 (K), R2.2
